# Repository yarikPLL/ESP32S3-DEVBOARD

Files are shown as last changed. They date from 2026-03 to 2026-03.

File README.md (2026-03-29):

# ESP32-S3 DevBoard (Recruitment Task)

This project is a custom development board based on the ESP32-S3, created as part of a recruitment task.  
Although the task was intended for candidates, I also completed it myself as a reference and benchmark solution.

## Overview

The board is based on the **ESP32-S3-WROOM-1** module and follows the general idea of standard development boards.

The pinout is **fully compatible with the original ESP32-S3 dev boards**, so it can be used as a drop-in replacement in typical setups.

## Features

- ESP32-S3-WROOM-1 module
- 2x USB Type-C connectors for power, programming, and communication OTG
- USB-to-UART converter based on **CP2102N** with auto-programming circuit
- IMU sensor (BMI270) connected via **I2C**
- 2x user LED indicators (0403) and UART led indicators
- Reset, boot and 2 users buttons
- DIP switch for flexible configuration

## Configuration (DIP Switch)

The board includes a DIP switch that allows:

- Enabling/disabling the USB-to-TTL converter  
- Enabling/disabling the IMU sensor  
- Powering off the ESP32 (useful when using the board purely as a USB-UART converter)

## IMU

An IMU sensor (BMI series) has been added and connected via the I2C interface.  
This allows easy integration of motion sensing features in future projects.

## USB to UART

The board includes a **CP2102N** USB-to-TTL converter with an auto-programming circuit, enabling:

- Firmware flashing
- Serial communication
- Seamless development workflow

## PCB Layout

Below are renders and layout views of the board:

### Layout
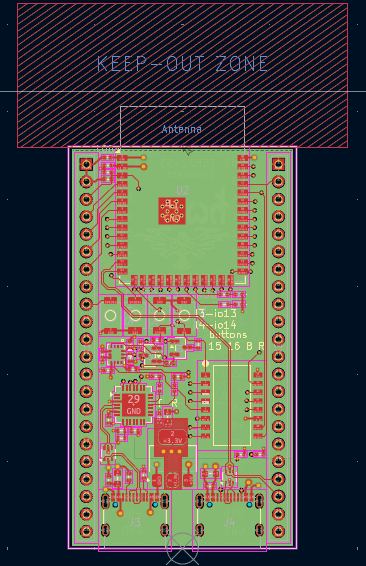
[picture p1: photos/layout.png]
PCB Layout


### 3D Views

#### Top View
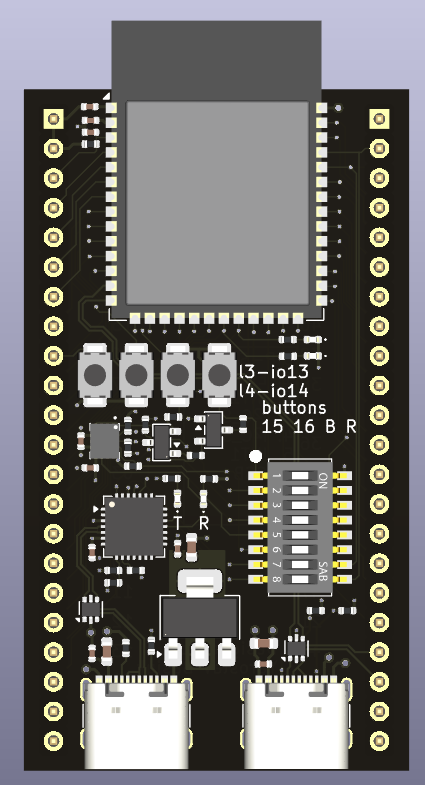
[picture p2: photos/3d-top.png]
3D Top


#### Bottom View
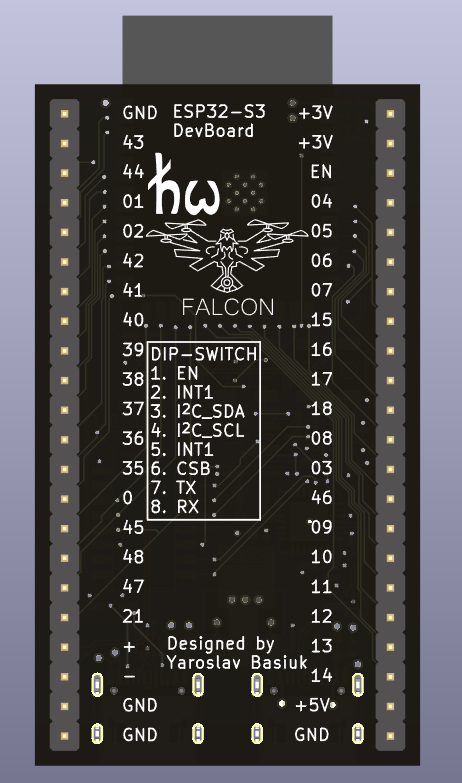
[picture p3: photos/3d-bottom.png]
3D Bottom


#### Isometric Top
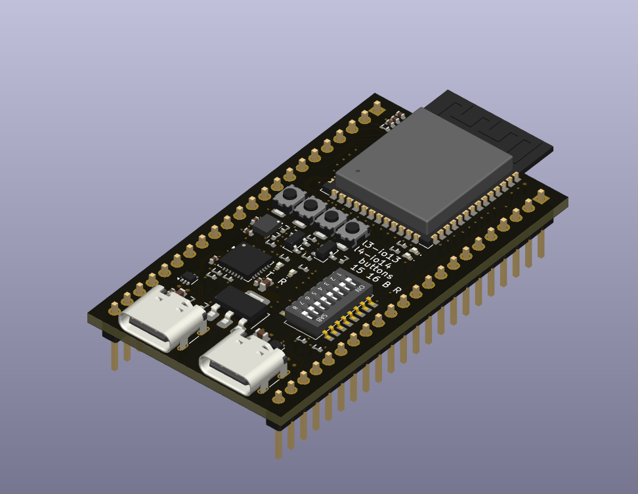
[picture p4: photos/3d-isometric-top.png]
3D Isometric Top


#### Isometric Bottom
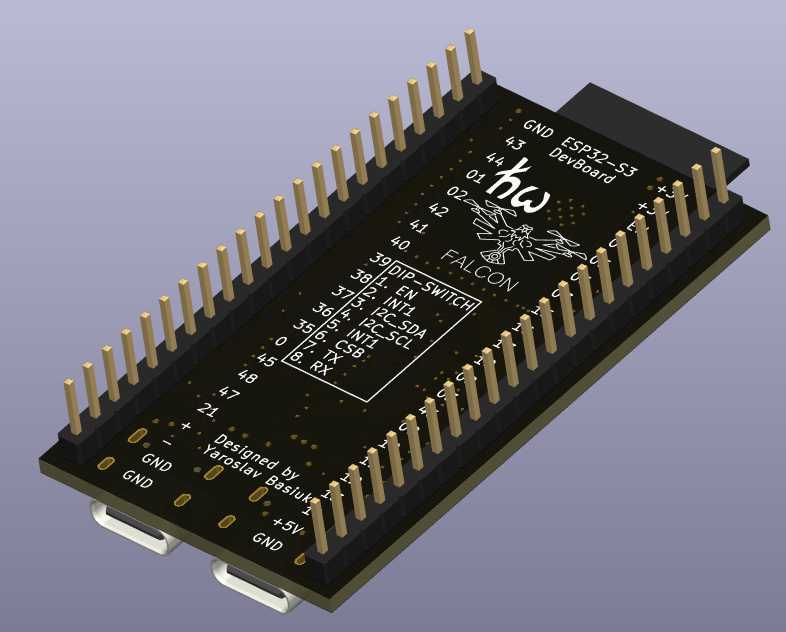
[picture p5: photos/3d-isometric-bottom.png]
3D Isometric Bottom


## Notes

This project was created as part of a recruitment process to evaluate practical hardware design skills, including:

- schematic design
- PCB layout
- manufacturability
- documentation

## License

This project is licensed under the GNU Lesser General Public License v2.1 (LGPL-2.1).

You are free to use, modify, and distribute this project under the terms of this license.

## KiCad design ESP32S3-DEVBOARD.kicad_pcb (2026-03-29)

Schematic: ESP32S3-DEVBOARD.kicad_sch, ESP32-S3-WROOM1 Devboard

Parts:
C1, C2, C4, C5, C7, C9, C11, C12, C13: 100n; C_0402_1005Metric; MFR Part # CL05B104KO5NNNC; LCSC C1525
C3, C6, C8: 10u_{ 20%}; C_0603_1608Metric; MFR Part # CL10A106MA8NRNC; LCSC C96446
C10, C15, C16: 100n; C_0402_1005Metric; MFR Part # CL05B104KO5NNNC; LCSC C1525; not fitted
C14: 10u_{ 20%}; C_0603_1608Metric; LCSC C96446; not fitted
D1, D3: RED; LED_0402_1005Metric; MFR Part # 16-213SDRC/S530-A3/TR8; LCSC C71911
D2, D4: GREEN; LED_0402_1005Metric; MFR Part # 16-213/GHC-YR1S1/3T; LCSC C74338
J1, J2: PinHeader_1x22_P2.54mm_Vertical; PinHeader_1x22_P2.54mm_Vertical_FLIPPED
J3, J4: G-Switch_GT-USB-7010ASV; USB_C_Receptacle_G-Switch_GT-USB-7010ASV; LCSC C2988369
Q1, Q2: BC817-40,215; LCSC C52801
R1, R5: 0R; R_0402_1005Metric; MFR Part # RC0402FR-070RL; LCSC C106231
R2, R3, R4, R8, R13, R14, R15: 10k; R_0402_1005Metric; MFR Part # RC0402FR-0710KL; LCSC C60490
R6, R7, R16, R17: 5.1k; R_0402_1005Metric; MFR Part # 0402WGF5101TCE; LCSC C25905
R9: 22.1k; R_0402_1005Metric; MFR Part # FRC0402F2212TS; LCSC C2929993
R10: 47.5k; R_0402_1005Metric; MFR Part # 0402WGF4752TCE; LCSC C25896
R11, R12, R20, R21: 1k; R_0402_1005Metric; MFR Part # 0402WGF1001TCE; LCSC C11702
SW1, SW2, SW3, SW4: TS-1088-AR02016; MFR Part # TS-1088-AR02016; LCSC C720477
SW5: SHOU_HAN_1.27-8P_TPPT; SHOU_HAN_1.27-8P_TTPT; MFR Part # 1.27-8P TPPT; LCSC C6386921
U1: AMS1117-3.3; LCSC C6186
U2: ESP32-S3-WROOM-1; LCSC C2913205
U3, U6: USBLC6-2P6; SOT-666; MFR Part # USBLC6-2P6; LCSC C2827693
U4: CP2102N-A02-GQFN28R; LCSC C964632
U5: BMI270; MFR Part # BMI270; LCSC C2836813

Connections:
+3.3V: C1.2, C2.2, C5.1, C6.1, C11.2, C12.1, C13.1, C16.1, J1.1, J1.2, R3.1, R8.1, R11.1, R12.1, R13.1, R14.1, SW5.11, U1.2 (VO), U2.2 (3V3), U4.6 (VDD), U5.5 (VDDIO), U5.8 (VDD)
+5V: C3.1, C4.1, C8.1, C9.1, C10.2, C14.1, C15.1, J1.21, J3.A4 (VBUS), J3.A9 (VBUS), J3.B4 (VBUS), J3.B9 (VBUS), J4.A4 (VBUS), J4.A9 (VBUS), J4.B4 (VBUS), J4.B9 (VBUS), R9.1, U1.3 (VI), U3.5 (VBUS), U6.5 (VBUS)
/CSB_U5: R15.1, SW5.6, U5.12 (CSB)
/DTR: Q2.3 (C), R2.2, U4.28 (~DTR)
/EN: C7.2, J1.3, R1.2, R3.2, SW1.2, SW5.1, U2.3 (EN)
/GPIO0: J2.14, R5.2, SW2.2, U2.27 (IO0)
/GPIO1: J2.4, U2.39 (IO1)
/GPIO2: J2.5, U2.38 (IO2)
/GPIO3: J1.13, U2.15 (IO3)
/GPIO4: J1.4, U2.4 (IO4)
/GPIO5: J1.5, U2.5 (IO5)
/GPIO6: J1.6, U2.6 (IO6)
/GPIO7: J1.7, U2.7 (IO7)
/GPIO8: J1.12, U2.12 (IO8)
/GPIO9: J1.15, U2.17 (IO9)
/GPIO10: J1.16, U2.18 (IO10)
/GPIO11: J1.17, U2.19 (IO11)
/GPIO12: J1.18, U2.20 (IO12)
/GPIO13: J1.19, R20.1, U2.21 (IO13)
/GPIO14: J1.20, R21.1, U2.22 (IO14)
/GPIO15: J1.8, SW3.1, U2.8 (IO15)
/GPIO16: J1.9, SW4.1, U2.9 (IO16)
/GPIO17: J1.10, U2.10 (IO17)
/GPIO18: J1.11, U2.11 (IO18)
/GPIO21: J2.18, SW5.12, U2.23 (IO21)
/GPIO35: J2.13, SW5.15, U2.28 (IO35)
/GPIO36: J2.12, U2.29 (IO36)
/GPIO37: J2.11, U2.30 (IO37)
/GPIO38: J2.10, U2.31 (IO38)
/GPIO39: J2.9, U2.32 (IO39)
/GPIO40: J2.8, U2.33 (IO40)
/GPIO41: J2.7, U2.34 (IO41)
/GPIO42: J2.6, U2.35 (IO42)
/GPIO43: J2.2, SW5.9, U2.37 (TXD0)
/GPIO44: J2.3, SW5.10, U2.36 (RXD0)
/GPIO45: J2.15, U2.26 (IO45)
/GPIO46: J1.14, U2.16 (IO46)
/GPIO47: J2.17, SW5.13, U2.24 (IO47)
/GPIO48: J2.16, SW5.14, U2.25 (IO48)
/INT1: SW5.2, U5.4 (INT1)
/INT2: SW5.5, U5.9 (INT2)
/I^{2}C_SCL: R14.2, SW5.4, U5.13 (SCX)
/I^{2}C_SDA: R13.2, SW5.3, U5.14 (SDX)
/RST: R8.2, U4.9 (~RST)
/RTS: Q1.2 (E), R4.2, U4.24 (~RTS)
/RX_LED: D2.1 (K), U4.18 (~RXT/GPIO.1)
/TX_LED: D1.1 (K), U4.19 (~TXT/GPIO.0)
/U2_RX: SW5.8, U4.25 (RXD)
/U2_TX: SW5.7, U4.26 (TXD)
/U2_VBUS: R9.2, R10.1, U4.8 (VBUS)
/USB0_D+: U3.6 (I/O1), U4.4 (D+)
/USB0_D-: U3.4 (I/O2), U4.5 (D-)
/USB0_T_D+: J3.A6 (D+), J3.B6 (D+), U3.1 (I/O1)
/USB0_T_D-: J3.A7 (D-), J3.B7 (D-), U3.3 (I/O2)
/USB1_D+: J2.19, U2.14 (USB_D+), U6.4 (I/O2)
/USB1_D-: J2.20, U2.13 (USB_D-), U6.6 (I/O1)
/USB1_T_D+: J4.A6 (D+), J4.B6 (D+), U6.3 (I/O2)
/USB1_T_D-: J4.A7 (D-), J4.B7 (D-), U6.1 (I/O1)
/USB_0_CC1: J3.A5 (CC1), R6.1
/USB_0_CC2: J3.B5 (CC2), R7.1
/USB_1_CC1: J4.A5 (CC1), R16.1
/USB_1_CC2: J4.B5 (CC2), R17.1
GND: C1.1, C2.1, C3.2, C4.2, C5.2, C6.2, C7.1, C8.2, C9.2, C10.1, C11.1, C12.2, C13.2, C14.2, C15.2, C16.2, D3.1 (K), D4.1 (K), J1.22, J2.1, J2.21, J2.22, J3.A1 (GND), J3.A12 (GND), J3.B1 (GND), J3.B12 (GND), J3.S1 (SHIELD), J4.A1 (GND), J4.A12 (GND), J4.B1 (GND), J4.B12 (GND), J4.S1 (SHIELD), R6.2, R7.2, R10.2, R15.2, R16.2, R17.2, SW1.1, SW2.1, SW3.2, SW4.2, SW5.16, U1.1 (GND), U2.1 (GND), U2.40 (GND), U2.41 (GND), U3.2 (GND), U4.3 (GND), U4.29 (GND), U5.6 (GNDIO), U5.7 (GND), U6.2 (GND)
unnamed: D1.2 (A), R11.2
unnamed: D2.2 (A), R12.2
unnamed: D3.2 (A), R20.2
unnamed: D4.2 (A), R21.2
unnamed: Q1.1 (B), R2.1
unnamed: Q1.3 (C), R1.1
unnamed: Q2.1 (B), R4.1
unnamed: Q2.2 (E), R5.1

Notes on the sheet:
ESP32-SR-WROOM-1
USB for OTG (ESP)
Auto program Circuit
Connecting TTL to ESP
Connecting IMU to ESP (INTR_{2})
Changing I^{2}C IMU Address
Connecting IMU to ESP (I^{2}C_SCL)
Power LDO 3.3V
USB for TTL
Interactive leds and buttons
Connecting IMU to ESP (INTR_{1})
IMU BMI270 I2C mode
Setting ESP to reset mode
Header pins P2.54mm
USB to TTL
DIP switch for connecting/disconnecting periferia
Connecting IMU to ESP (I^{2}C_SDA)

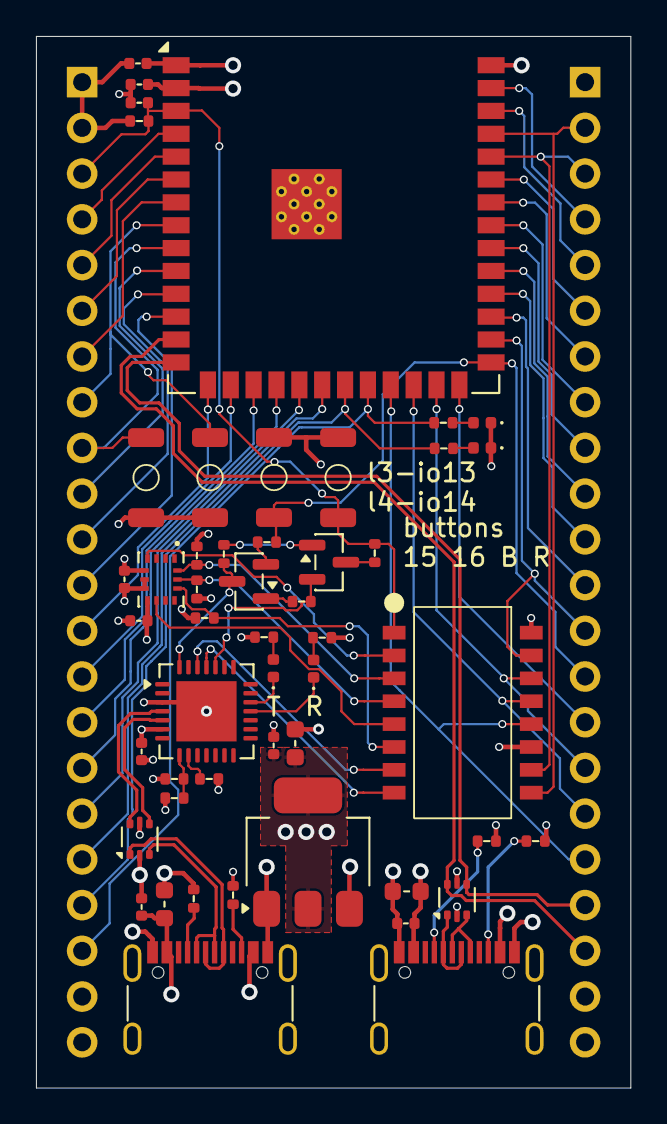
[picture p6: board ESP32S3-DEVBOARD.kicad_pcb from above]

Board: 4 copper layers, 33.0 x 58.4 mm, 52 parts (0 on the bottom side), 71 nets.

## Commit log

2026-03-20 Created an empty Kicad project
    [ESP32S3-DEVBOARD.kicad_pcb, ESP32S3-DEVBOARD.kicad_sch]
2026-03-21 Created library for USB_C, ESP32, AND CP2102N, starded to draw schematic
    [ESP32S3-DEVBOARD.kicad_sch]
2026-03-22 Add goldpin, add LDO
    [ESP32S3-DEVBOARD.kicad_sch]
2026-03-22 Add decoupling capacitors
    [ESP32S3-DEVBOARD.kicad_sch]
2026-03-23 Add two resisotrs to library
    [ESP32S3-DEVBOARD.kicad_sch]
2026-03-24 Add 1k resistors and leds (red and green 0402)
    [ESP32S3-DEVBOARD.kicad_sch]
2026-03-24 Add buttons to lib, 0R resistors and LEDS
    [ESP32S3-DEVBOARD.kicad_sch]
2026-03-24 Add marks, only imu left
    [ESP32S3-DEVBOARD.kicad_sch]
2026-03-24 Finnished a schematic. Rev 1.0.0
    [ESP32S3-DEVBOARD.kicad_sch]
2026-03-24 Created pcb project and defined design rules
    [ESP32S3-DEVBOARD.kicad_pcb]
2026-03-25 Started to rout USB, need swap ports for uart
    [ESP32S3-DEVBOARD.kicad_pcb, ESP32S3-DEVBOARD.kicad_sch]
2026-03-25 Swap usb ports, need to define differential pair
    [ESP32S3-DEVBOARD.kicad_pcb]
2026-03-26 Defined netclasses for USB
    [ESP32S3-DEVBOARD.kicad_pcb, ESP32S3-DEVBOARD.kicad_sch]
2026-03-26 Routed USB and added uart jumpers
    [ESP32S3-DEVBOARD.kicad_pcb, ESP32S3-DEVBOARD.kicad_sch]
2026-03-26 Removed jumpers, and added dipswitch to schematics
    [ESP32S3-DEVBOARD.kicad_pcb, ESP32S3-DEVBOARD.kicad_sch]
2026-03-26 Changet position of ttl
    [ESP32S3-DEVBOARD.kicad_pcb, ESP32S3-DEVBOARD.kicad_sch]
2026-03-27 Routing usb for ttl
    [ESP32S3-DEVBOARD.kicad_pcb]
2026-03-27 started to wotk on another laptop
    [ESP32S3-DEVBOARD.kicad_pcb]
2026-03-28 finish componemt placement
    [ESP32S3-DEVBOARD.kicad_pcb, ESP32S3-DEVBOARD.kicad_sch]
2026-03-28 fixed all errors (edit footprint silkskreens)
    [ESP32S3-DEVBOARD.kicad_pcb, ESP32S3-DEVBOARD.kicad_sch]
2026-03-29 Finnished the board!! :)
    [ESP32S3-DEVBOARD.kicad_pcb, ESP32S3-DEVBOARD.kicad_sch]
2026-03-29 fixed BOM
    [ESP32S3-DEVBOARD.kicad_pcb, ESP32S3-DEVBOARD.kicad_sch]
